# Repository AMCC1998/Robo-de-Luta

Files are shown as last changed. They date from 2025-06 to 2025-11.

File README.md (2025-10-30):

# 🤖 Projeto: Robô Battle Bot - Rumo à Robot Extreme Competition

Este é o repositório do projeto dedicado ao desenvolvimento e construção de um robô de combate, totalmente inspirado nas competições de **Battle Bots** e com o objetivo final de participar na **Robot Extreme Competition**.

---

## 📖 Sobre o Projeto

A inspiração para este projeto vem da minha paixão de longa data pela **Battle Bots**, uma competição global que é o epicentro da engenharia e inovação em robótica de combate.

O objetivo principal é conceber e construir um **robô de combate funcional e competitivo, desenvolvido totalmente desde o zero**, capaz de enfrentar adversários na categoria adequada da Robot Extreme Competition.

## 🛠️ Desenvolvimento e Features

O desenvolvimento tem sido focado nas seguintes áreas principais:

### 1. Design Estrutural e Mobilidade

* **Chassis:** Construção de um chassis robusto e resistente, projetado para absorver e suportar impactos intensos.
* **Mobilidade:** Implementação de um sistema de mobilidade eficiente, essencial para manobras rápidas e posicionamento tático na arena.
* **Estrutura:** O design geral da estrutura foi otimizado para o combate, equilibrando peso, proteção e distribuição de componentes.

### 2. Sistemas de Ataque e Defesa

* Desenvolvimento de **armas e proteções** personalizadas e alinhadas com as regras específicas da competição.

## ⚙️ Destaque: A Arma Maquinada em CNC

A peça central do poder de ataque do robô é a sua arma principal.

| Característica | Detalhe |
| :--- | :--- |
| **Material** | Alumínio (Al) |
| **Processo** | Maquinação de Alta Precisão (CNC) |
| **Design** | Peça desenhada à medida para máxima eficácia e durabilidade. |
| **Parceria** | Execução do serviço de maquinação pela **JLCCNC**. |
| **Resultado** | Detalhe impecável nas componentes e excelente precisão de execução. |

A maquinação em CNC garantiu a obtenção de uma arma leve, resistente e com a geometria exata necessária para o combate.

## 🎥 Acompanhe a Jornada

Todo o processo de design, construção, parcerias e testes está a ser documentado numa série dedicada.

Segue a jornada completa e todos os detalhes técnicos no meu canal:

🔗 **[https://youtube.com/@amcc_projects?si=A5bpC3iiJzzU8RSe]** (Insira o link da playlist/canal aqui)

## 🎯 Próximos Passos

Os próximos marcos no desenvolvimento incluem:

* **Testes de Performance:** Avaliação da mobilidade, resistência do chassis e estabilidade em condições de combate simuladas.
* **Integração Eletrónica:** Instalação e programação dos sistemas de controlo, motores e bateria.
* **Ajustes Finais:** Otimização dos sistemas de arma e defesa com base nos resultados dos testes.
* **Competir:** Preparação para a **Robot Extreme Competition**!

🔗 **[JLCCNC - Consultoria e Soluções](https://jlccnc.com/?from=AndreCarvalho)**

🔗 **[Website](https://amccweb.com/)**

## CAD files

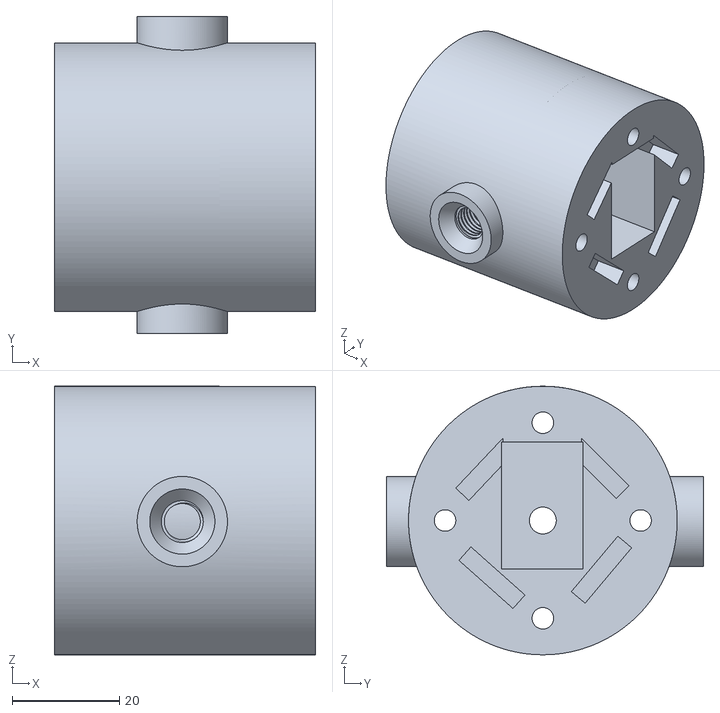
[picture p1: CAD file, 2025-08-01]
01.ficheiros_3d/arma/Botzilla_arma_3.stl
48.6 x 59.0 x 50.0

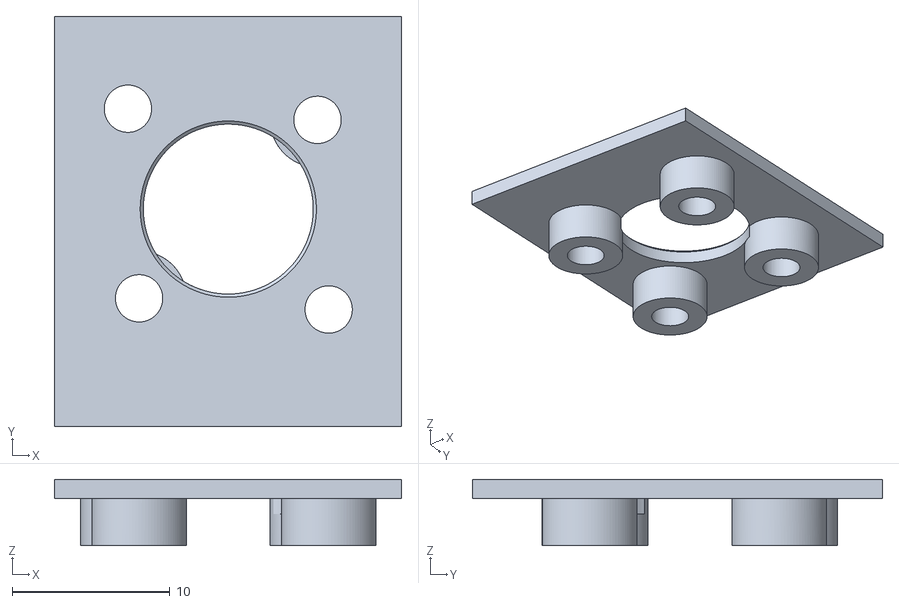
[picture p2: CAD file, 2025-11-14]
01.ficheiros_3d/teste_furacoes_motor.stl
22.0 x 26.0 x 4.20

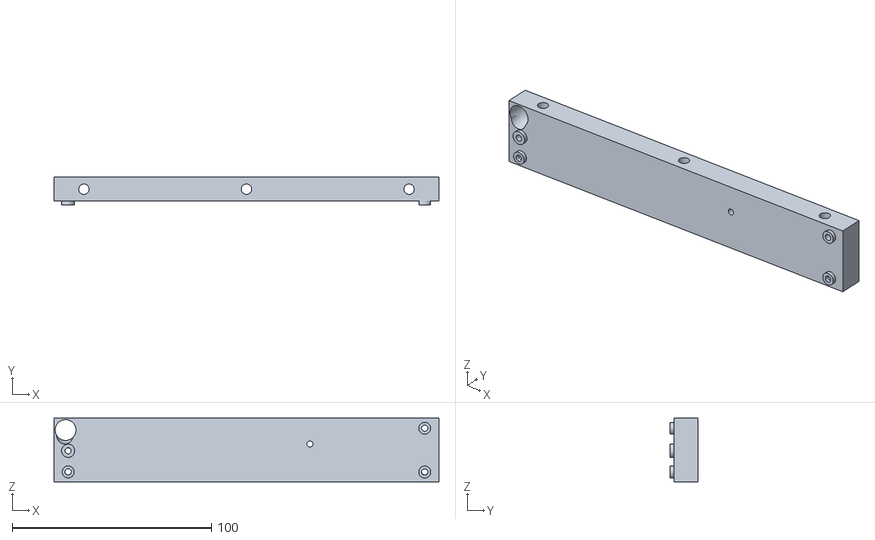
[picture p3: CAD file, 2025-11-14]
01.ficheiros_3d/v2/peca_frente.stl
193.0 x 13.8 x 32.0

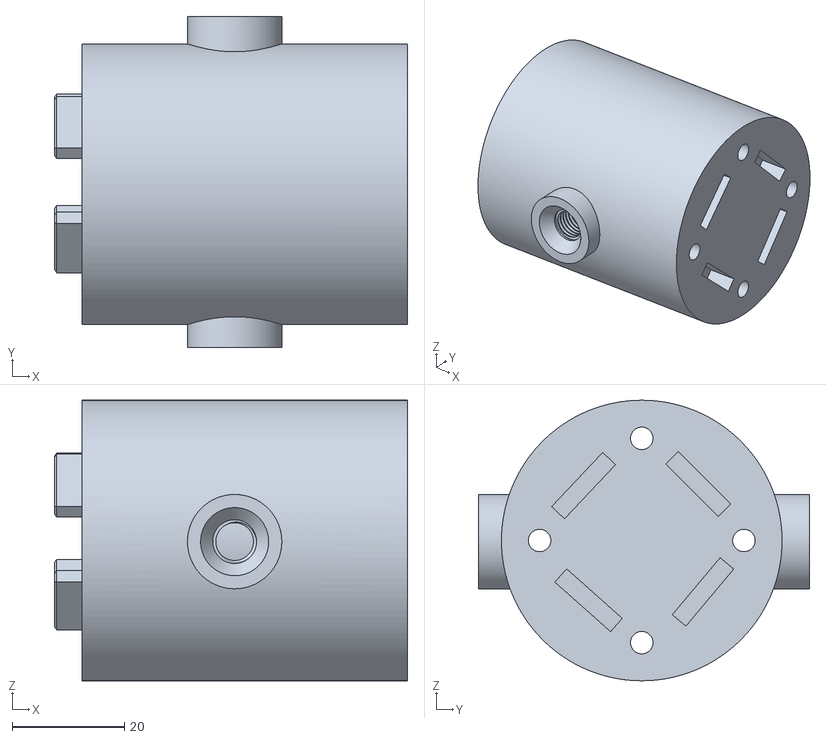
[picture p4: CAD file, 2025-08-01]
01.ficheiros_3d/arma/Botzilla_arma_2.stl
62.9 x 59.0 x 50.0

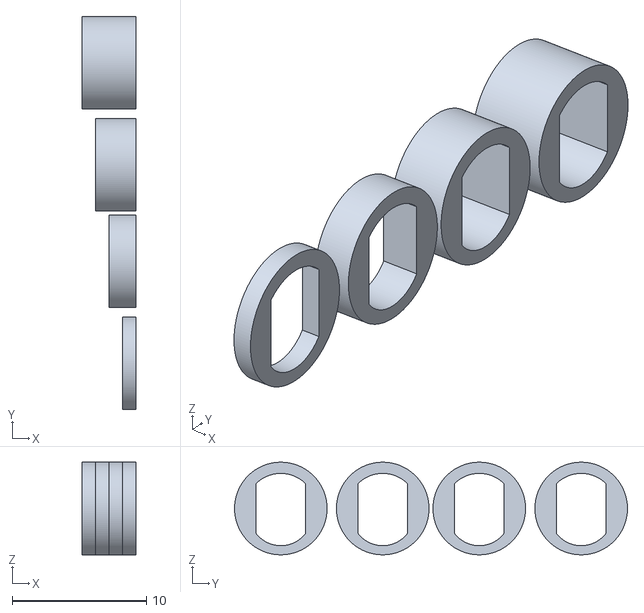
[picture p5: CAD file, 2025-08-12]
01.ficheiros_3d/Botzilla_espacadores_roda.stl
4.00 x 29.3 x 6.91

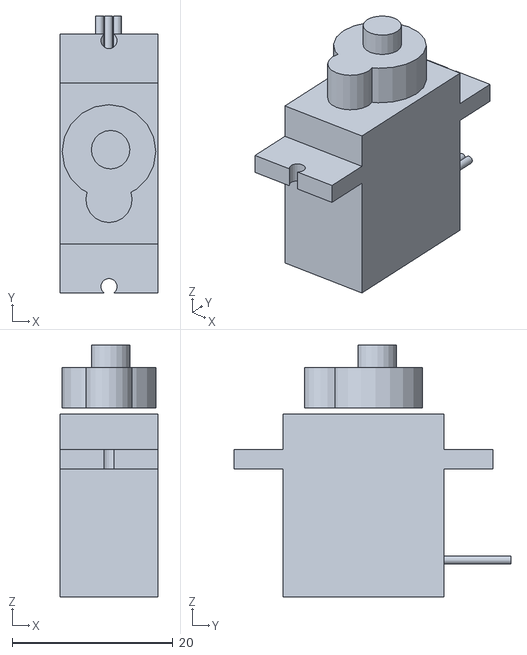
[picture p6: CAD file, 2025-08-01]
01.ficheiros_3d/Elementos_design/Frantic Blad-Trug.stl
12.2 x 34.5 x 31.3

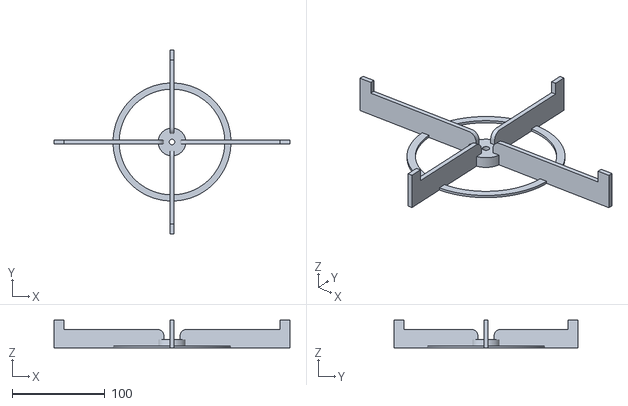
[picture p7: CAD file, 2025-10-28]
01.ficheiros_3d/v2/suporte cima.stl
254.0 x 198.5 x 30.0

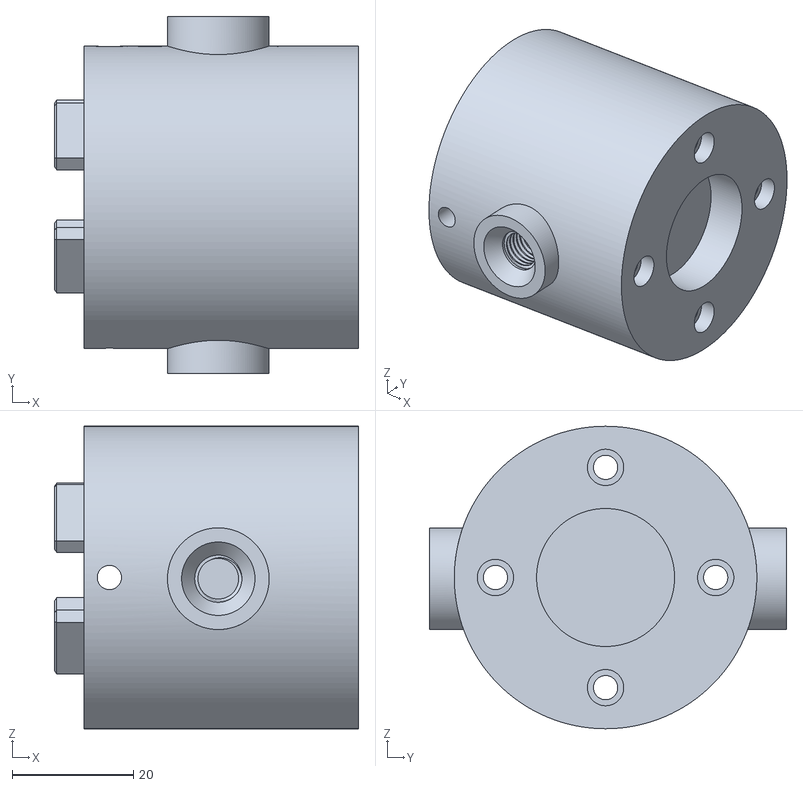
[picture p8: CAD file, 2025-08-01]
01.ficheiros_3d/arma/Botzilla_arma_1.stl
50.3 x 59.0 x 50.0

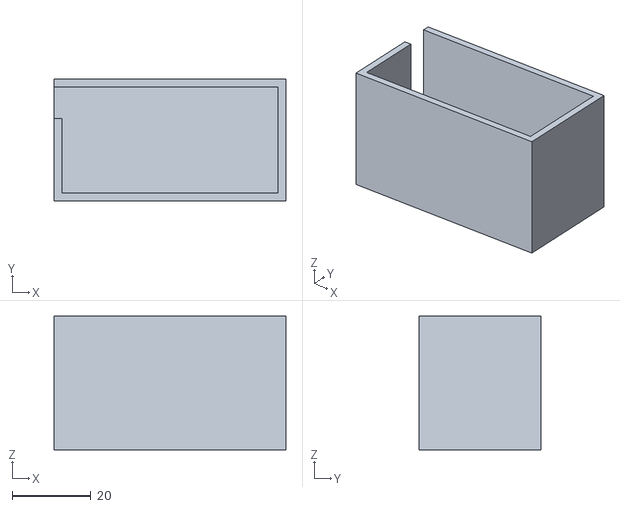
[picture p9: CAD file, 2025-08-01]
01.ficheiros_3d/Botzilla_caixa_bateria.stl
59.0 x 31.0 x 34.0

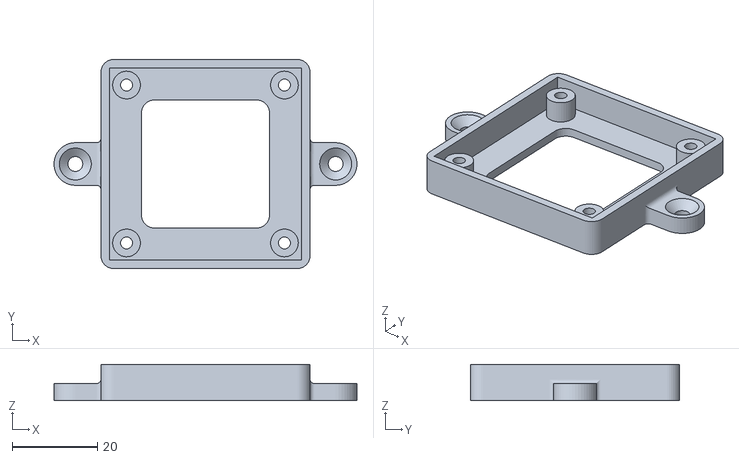
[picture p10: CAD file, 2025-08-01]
01.ficheiros_3d/Elementos_design/mnt298bracket.stl
71.0 x 49.0 x 8.50

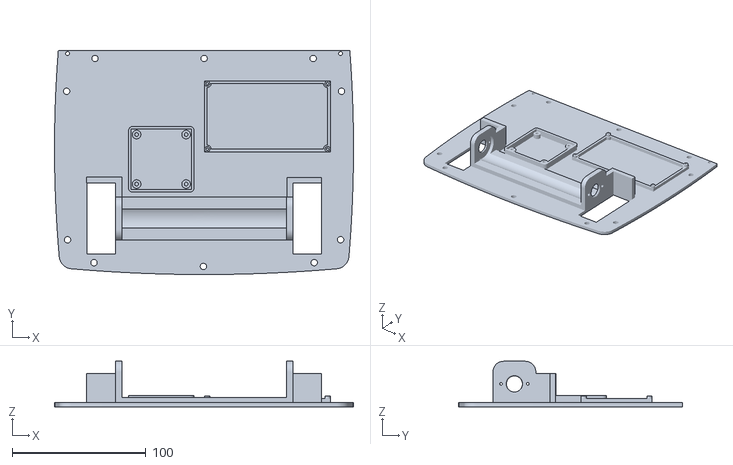
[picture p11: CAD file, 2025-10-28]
01.ficheiros_3d/v2/v2.stl
223.4 x 167.4 x 34.0

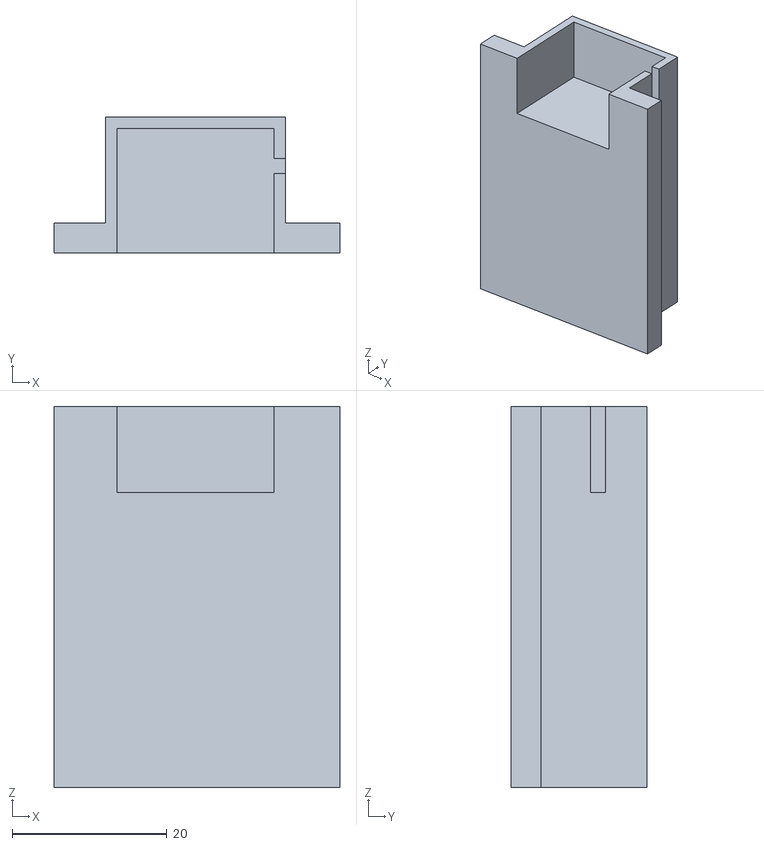
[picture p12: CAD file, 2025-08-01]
01.ficheiros_3d/Botzilla_suporte_servo.stl
37.0 x 17.6 x 49.3

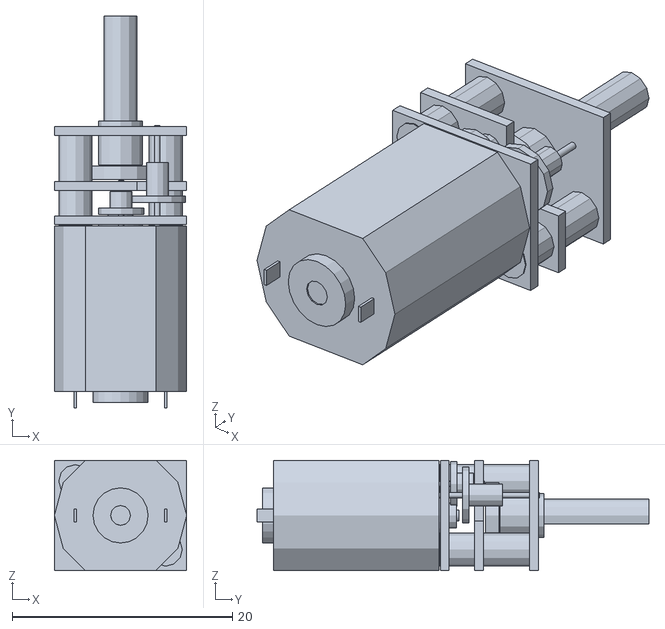
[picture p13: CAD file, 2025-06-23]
01.ficheiros_3d/Elementos_design/motor.stl
12.0 x 35.6 x 10.0

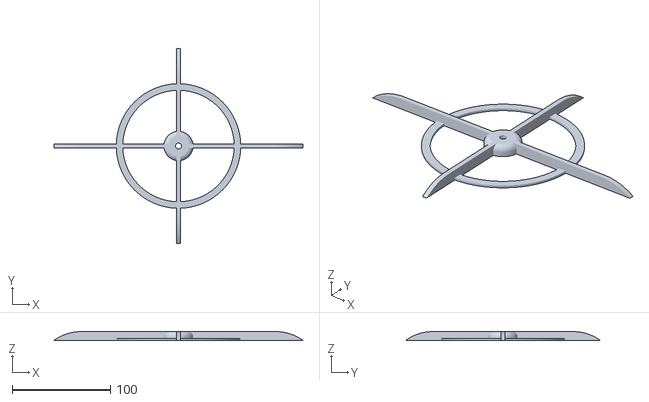
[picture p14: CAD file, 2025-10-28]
01.ficheiros_3d/v2/suporte baixo.stl
254.0 x 198.5 x 9.00

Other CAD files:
01.ficheiros_3d/Botzilla_braco_servo.stl
01.ficheiros_3d/Tampa_superior_nova.stl
01.ficheiros_3d/v2/Botzilla_frame_esquerda.stl
01.ficheiros_3d/suporte_arma_esq.stl
01.ficheiros_3d/Botzilla_lateral_dir.stl
01.ficheiros_3d/Botzilla_lateral_esq.stl
01.ficheiros_3d/Elementos_design/Frantic Blad-Trug (1).stl
01.ficheiros_3d/Tampa_superior_1mm.stl
01.ficheiros_3d/base_baixo.stl
01.ficheiros_3d/body_frente.stl
01.ficheiros_3d/body_tras.stl
01.ficheiros_3d/cabo_ferramenta_bloqueio.stl
01.ficheiros_3d/molde_pneu_roda.stl
01.ficheiros_3d/molde_roda_Rodas.stl
01.ficheiros_3d/roda.stl
01.ficheiros_3d/suporte_arma_dir.stl
01.ficheiros_3d/suporte_motor.stl
01.ficheiros_3d/v2/Arma (1) (1).step
01.ficheiros_3d/v2/Arma (1) (2).f3d
01.ficheiros_3d/v2/Arma (1) (2).step
01.ficheiros_3d/v2/Arma (1).step
01.ficheiros_3d/v2/Arma (2).step
01.ficheiros_3d/v2/Arma.step
01.ficheiros_3d/v2/Arma_1.stl
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

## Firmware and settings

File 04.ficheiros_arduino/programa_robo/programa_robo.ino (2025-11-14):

#include <IBusBM.h>
#include <Servo.h>

IBusBM IBus;

unsigned long lastChangeTime = 0;
bool failsafe = false;

int last_acel = 0;
int last_dir = 0;
int last_arma = 0;

int tempoFailSafe = 3000;

Servo esc;
const int motorArma = 3;
const int velocidadeMinima = 1000;

// Motor A
int pwmA = 5;
int dirA = A0;

// Motor B
int pwmB = 6;
int dirB = A1;

void ativaArma(int velocidadeArma = velocidadeMinima);
void desativaArma();

void moverFrente(int velocidade);
void moverTras(int velocidade);
void virarEsquerda(int velocidade);
void virarDireita(int velocidade);
void parar();

void setup() {
  Serial.begin(115200);

  pinMode(pwmA, OUTPUT);
  pinMode(dirA, OUTPUT);

  pinMode(pwmB, OUTPUT);
  pinMode(dirB, OUTPUT);

  parar();
  esc.attach(motorArma);
  esc.writeMicroseconds(1200);
  delay(200);
  esc.writeMicroseconds(0);

  IBus.begin(Serial1);
  Serial.println("Inicializacao completa");
  parar();
  lastChangeTime = millis();
}

// Mapeia canal iBUS (1000-2000) para valor entre -255 e 255 com zona morta
int mapChannelToPWM(uint16_t val) {
  int pwm = map(val, 1000, 2000, -255, 255);
  if (abs(pwm) < 20) pwm = 0;  // zona morta
  pwm = pwm > 255 ? 255 : pwm;
  return pwm;
}

void loop() {
  parar();
  IBus.loop();

  int acel = mapChannelToPWM(IBus.readChannel(2));  // aceleração -255 a 255
  int dir = mapChannelToPWM(IBus.readChannel(3));   // direção -255 a 255
  uint16_t canalArma = IBus.readChannel(4);

  if (acel < -300) {
    parar();
    return;
  }


  //**************************** FAIL SAFE ****************************************
  // Verifica se houve alguma mudança
  if (acel != last_acel || dir != last_dir || canalArma != last_arma) {
    last_acel = acel;
    last_dir = dir;
    last_arma = canalArma;
    lastChangeTime = millis();
    failsafe = false;
  } else {
    // Se nada mudou em 500 ms → FAILSAFE
    if (millis() - lastChangeTime > tempoFailSafe) {
      failsafe = true;
    }
  }

  // Fail-safe ativo → parar tudo
  if (failsafe) {
    parar();
    desativaArma();
    Serial.println("⚠️ FAILSAFE — sem sinal!");
    delay(50);
    return;
  }
  // ****************************************************************



  //Positivar a velocidade
  int velocidade = acel < 0 ? acel * -1 : acel;

  if (dir < -30) {
    velocidade = dir < 0 ? dir * -1 : dir;
    virarEsquerda(velocidade);
  } else if (dir > 30) {
    velocidade = dir < 0 ? dir * -1 : dir;
    virarDireita(velocidade);
  } else if (acel > 10) {
    moverFrente(velocidade);
  } else if (acel < -10) {  // garante os limites
    moverTras(velocidade);
  } else {
    parar();
  }

  // Controle da arma no canal 3 (index 2)

  if (canalArma > 1500) {
    ativaArma(1200);
  } else {
    desativaArma();
  }


  // Controle da arma no canal 7 servo Virar o robo
  uint16_t canalServo = IBus.readChannel(6);
  //Serial.print("Canal servo: ");
  //Serial.println(canalServo);
  if (canalServo > 2005) {
    //ativaArma(1200);
  } else {
    //desativaArma();
  }


  Serial.print("Acel: ");
  Serial.print(acel);
  Serial.print("\tDir: ");
  Serial.print(dir);
  Serial.print("\tArma: ");
  Serial.println(canalArma);

  delay(10);
}

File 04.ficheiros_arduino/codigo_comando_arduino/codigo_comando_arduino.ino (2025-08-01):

String version = "1.0";

#include <Wire.h>
#include "SSD1306Ascii.h"
#include "SSD1306AsciiWire.h"

#include "fonts/TimesNewRoman13.h"
#include "fonts/TimesNewRoman16.h"
#include "fonts/Stang5x7.h"



// ********************** Ecra **************************
SSD1306AsciiWire oled;

const uint8_t* currentFont;

void clearCenteredText(const char* text, int row, int charWidth = 6, int startCol = -1);
void clearLine(const char* text, int row, int charWidth = -1, int startCol = -1);
// *******************************************************




// Joystick 1 (esquerdo)
const int VRy1 = A1;  // Frente/Trás
const int VRx1 = A0;  // Esquerda/Direita
const int SW1 = 9;    // Botão joystick 1

// Joystick 2 (direito)
const int VRy2 = A3;  // Frente/Trás
const int VRx2 = A2;  // Esquerda/Direita
const int SW2 = 8;    // Botão joystick 2

const int limiar = 100;
const int centro = 512;

String comando = "";
String ultimoComando = "";

void setup() {
  Serial.begin(9600);
  Serial1.begin(9600);
  delay(1000);
  pinMode(SW1, INPUT_PULLUP);
  pinMode(SW2, INPUT_PULLUP);
  Wire.setClock(400000);

  //Ecra
  // Use next line if no RST_PIN or reset is not required.
  Wire.begin();                       // Inicializa I2C hardware
  oled.begin(&Adafruit128x64, 0x3C);  // Endereço I2C padrão
  oled.clear();

  screenSetFont(Stang5x7);
  oled.setCursor(0, 0);
  oled.print("V: " + version);

  oled.setCursor(70, 0);
  oled.print("Loading...");

  screenSetFont(TimesNewRoman16);
  printCentered("Bem Vindo!", 3);

  screenSetFont(Stang5x7);
  printCentered("amcc_projects 2025", 7);

  delay(2000);

  oled.clear();
  screenSetFont(Stang5x7);
  oled.setCursor(0, 0);
  oled.print("V: " + version);
  oled.setCursor(81, 0);
  oled.print("Bat: 60%");
  screenSetFont(TimesNewRoman16);
  printCentered(("Send: " + comando).c_str(), 3);
}

void loop() {


  int y1 = analogRead(VRy1);
  int x1 = analogRead(VRx1);
  int y2 = analogRead(VRy2);
  int x2 = analogRead(VRx2);

  // --- Joystick 1 (esquerdo) ---
  if (y1 < centro - limiar) {
    comando = "1T" + String(1023 - y1);
  } else if (y1 > centro + limiar) {
    comando = "1F" + String(y1);
  }

  if (x1 < centro - limiar) {
    comando = "1D" + String(1023 - x1);  // Direita
  } else if (x1 > centro + limiar) {
    comando = "1E" + String(x1);  // Esquerda
  }

  if (digitalRead(SW1) == LOW) {
    comando = "J1";
    delay(100);  // Joystick 1 pressionado
  }

  // --- Joystick 2 (direito) ---
  if (y2 < centro - limiar) {
    comando = "2T" + String(1023 - y2);
  } else if (y2 > centro + limiar) {
    comando = "2F" + String(y2);
  }

  if (x2 < centro - limiar) {
    comando = "2D" + String(1023 - x2);
  } else if (x2 > centro + limiar) {
    comando = "2E" + String(x2);
  }

  if (digitalRead(SW2) == LOW) {
    comando = "J2";
    delay(100);  // Joystick 2 pressionado
  }

  Serial1.print(comando);



  if (comando != ultimoComando) {
    int charWidth = 6;  // ou 10 se for TimesNewRoman16
    String texto = "Send: " + comando;

    clearLine(texto.c_str(), 3, charWidth, 60);
    printCentered(texto.c_str(), 3);
  }

  ultimoComando = comando;
  delay(100);
}

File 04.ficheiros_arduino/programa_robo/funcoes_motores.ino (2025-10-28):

// Funções de movimento
void moverFrente(int velocidade) {
  digitalWrite(dirA, LOW);
  digitalWrite(dirB, LOW);
  analogWrite(pwmA, velocidade);
  analogWrite(pwmB, velocidade);
}

void moverTras(int velocidade) {
  velocidade = 255 - constrain(velocidade, 0, 255);  // inverte
  digitalWrite(dirA, HIGH);
  digitalWrite(dirB, HIGH);
  analogWrite(pwmA, velocidade);
  analogWrite(pwmB, velocidade);
}

void virarEsquerda(int velocidade) {
  digitalWrite(dirA, HIGH);
  digitalWrite(dirB, LOW);
  analogWrite(pwmB, velocidade);
  velocidade = 255 - constrain(velocidade, 0, 255);  // inverte
  analogWrite(pwmA, velocidade);
}

void virarDireita(int velocidade) {
  digitalWrite(dirA, LOW);
  digitalWrite(dirB, HIGH);
  analogWrite(pwmA, velocidade);
  velocidade = 255 - constrain(velocidade, 0, 255);  // inverte
  analogWrite(pwmB, velocidade);
}

void parar() {
  digitalWrite(dirB, LOW);
  analogWrite(pwmB, 0);
  analogWrite(pwmA, 0);
  digitalWrite(dirA, LOW);
}

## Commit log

2025-06-23 Ficheiros 3d
    [molde_pneu_roda.stl, molde_roda_Rodas.stl, motor.stl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]
2025-06-23 Add 3D model file arma_rolo.stl
    Added a new STL file for the 3D model 'arma_rolo' to the 01.ficheiros_3d directory.
2025-08-12 Add new 3D files and update robot control logic
    Added new STL files for Botzilla components and a photograph. Updated programa_robo.ino to adjust direction and acceleration thresholds, increase weapon activation value, add servo control logic, and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
    [Body 44.stl, Botzilla_espacadores_roda.stl, Circular Pattern 01.stl]
2025-10-28 Alterações a ficheiros desnecessários
    [Arma (1) (1).step, Arma (1) (2).f3d, Arma (1) (2).step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]
2025-11-14 Correções peças STL
    [peca_frente.stl, suporte arma esq.stl, teste_furacoes_motor.stl]
